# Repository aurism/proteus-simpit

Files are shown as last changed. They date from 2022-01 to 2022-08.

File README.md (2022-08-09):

# Proteus Simpit
Proteus is a flight simpit designed to fit under a standard rolling office chair, and can mount different joystick, throttle, collective, and rudder modules. Legs on the simpit frame hold the chair suspended in the air, guaranteeing that the seat will not roll or rotate. The simpit folds up when not in use, and features retractable wheels to allow the setup to easily roll out of the way. The frame is constructed mostly from off the shelf aluminum framing components.

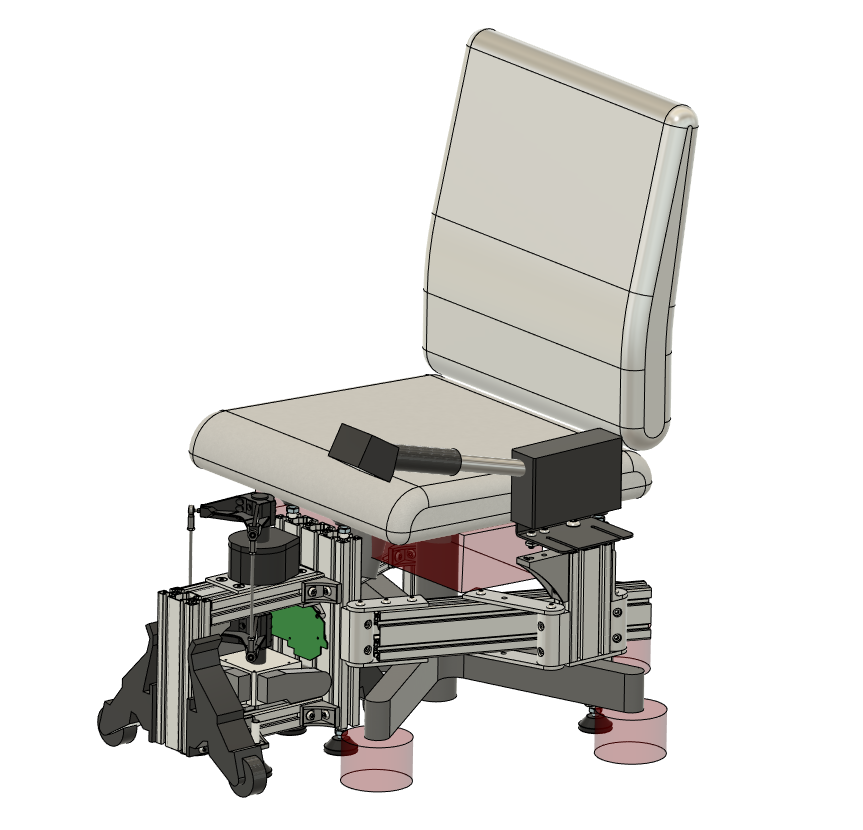
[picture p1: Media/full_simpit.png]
Full Simpit


The Puppetmaster joystick module is the main part of the Proteus simpit. It combines the force feedback capabilities of a Microsoft Sidewinder Force Feedback 2 with the precision and increased button count of a modern flight stick. A bare Microsoft force feedback gimbal is mounted on the bottom of the Puppetmaster frame and is mechanically coupled to a flight stick on top of the frame. Because it uses the original Microsoft Force Feedback 2 PCB, all original DirectInput force feedback effects are supported. Currently, the VKB Gunfighter MkIII with stick extension is used as the flight stick, but you could modify the design to support any other flight stick with a stick extension. The Puppetmaster frame is constructed from off the shelf aluminum framing components and 3D printed parts.

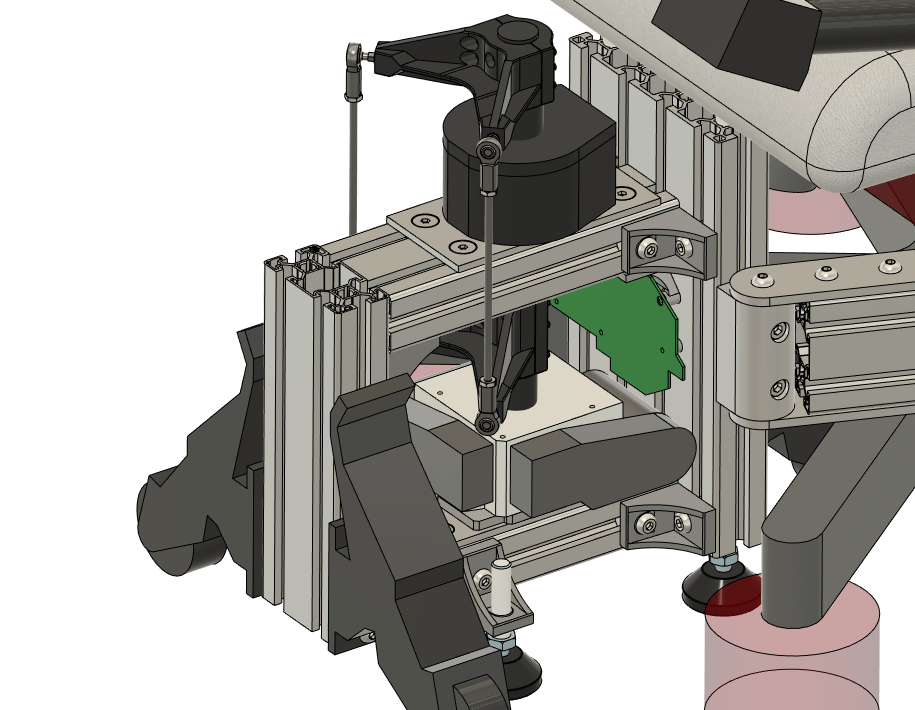
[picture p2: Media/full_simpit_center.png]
Full Simpit Center


## Current Configurations
* Proteus Simpit With All Modules
  * Mounts GF3 Puppetmaster Joystick Module in center
  * Mounts K51 Collective Module on left swingarm
  * Total cost: $1483

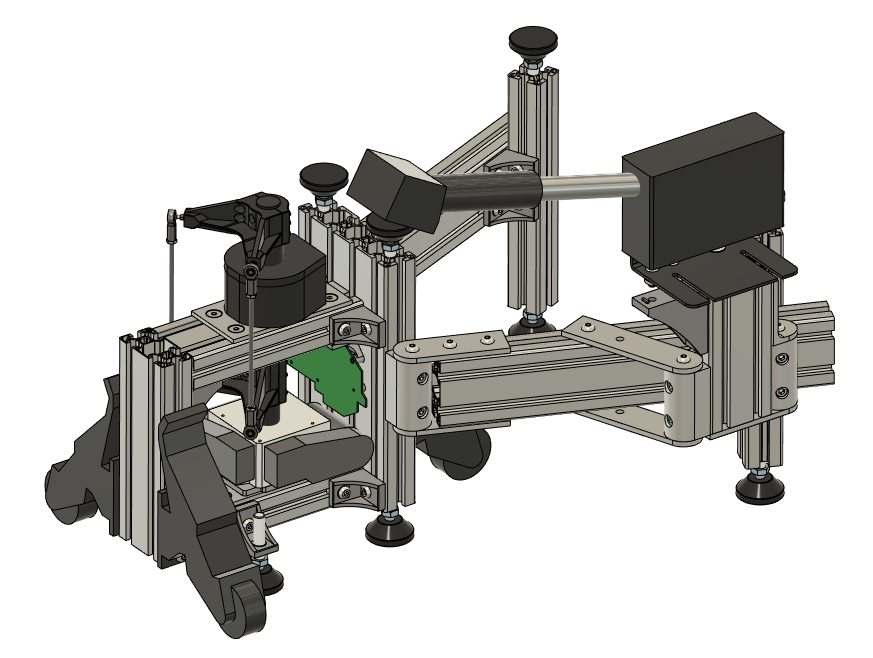
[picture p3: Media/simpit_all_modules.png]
Simpit with All Modules
  

* GF3 Puppetmaster Standalone Joystick
  * Mounts GF3 Puppetmaster Joystick Module on free standing feet
  * Total cost: $892

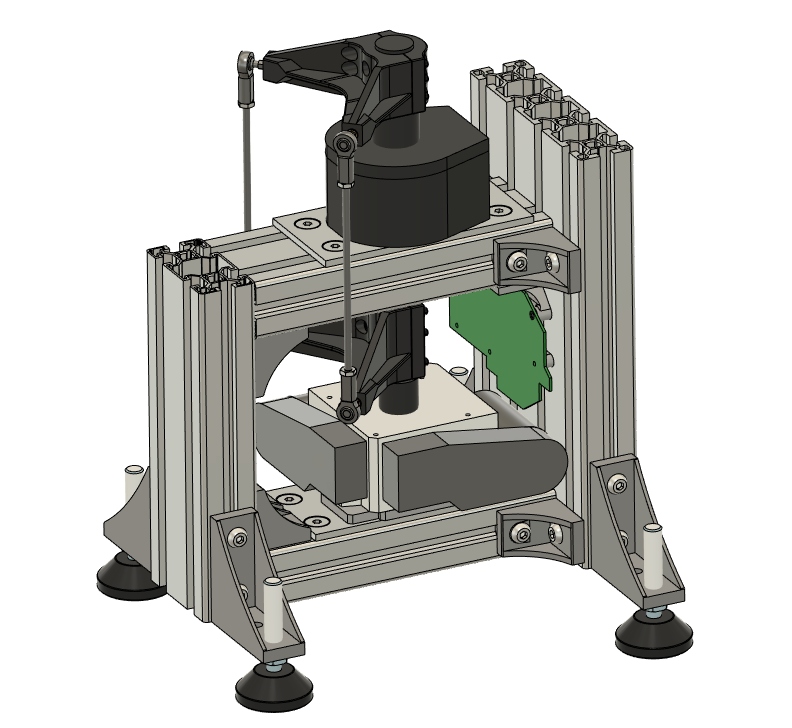
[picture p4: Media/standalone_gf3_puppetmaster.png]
Standalone GF3 Puppetmaster
  

## Current Modules
* GF3 Puppetmaster Joystick Module
  * Mounts a VKB Gunfighter MkIII with stick extension
  * Uses a Microsoft Sidewinder Force Feedback 2 gimbal
  * Cost of parts other than VKB Gunfighter MkIII: $336
  * Total cost: $795

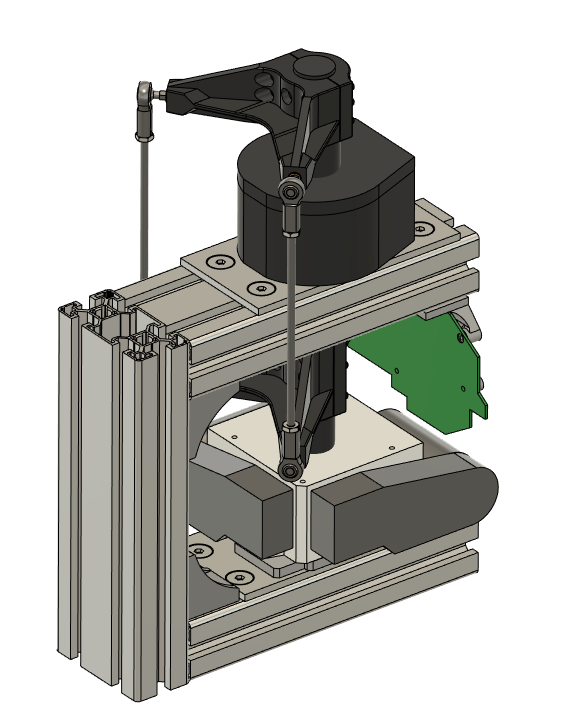
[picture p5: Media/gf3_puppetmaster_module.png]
GF3 Puppetmaster Module
  

* K51 Collective Module
  * Mounts a K-51 collective
  * Cost of parts other than K-51: $6
  * Total cost: $303

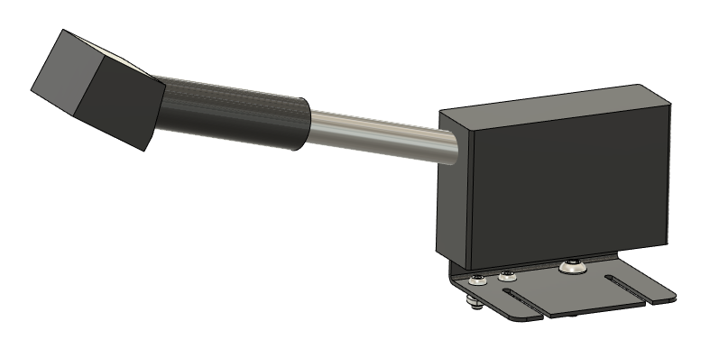
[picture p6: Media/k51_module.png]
K51 Collective Module
  

* Notionally plan to add more modules in the future

## Files and Instructions
The following files are included in each module's folder:
* CAD files, Fusion 360 and STEP format
* Drawings (if relevant)
* 3D Print Files, STL format (if relevant)
* Build instructions
* BOM

## Technical Notes
* Out of the box, the FFB gimbal does not have enough torque to adequately drive a flightstick with stick extension. Thus, the assembly instructions for the Puppetmaster joystick module includes steps to solder resistors to the FFB PCB to double the motor torque, using the method described by [Roland van Roy](http://www.simprojects.nl/ms_siderwinder_ff2_hack.htm) and others.
* With the above resistor mod, the Puppetmaster joystick produces 1.7 N-m of torque max (after subtracting torque due to friction). This feels roughly equivalent to a medium-light spring loaded cam. When held at max torque, there does not seem to be a torque falloff with time. By comparison, the Brunner CLS-E is advertised at 4.2 N-m of torque. However this [review](https://www.reddit.com/r/hoggit/comments/hu4uif/comment/fylmze2/?utm_source=share&utm_medium=web2x&context=3) states that it actually maxes out at 3.6 N-m and gradually falls off to 1.4 N-m over ~40s.
* The Puppetmaster joystick has a bit of a vague-feeling center, meaning that trimming to a certain position is less precise than desirable. Measuring from the top of the grip, the stick can be moved in roughly a 15mm diameter circle with little to no centering feeling. When the gear on the motor is clamped and prevented from turning, the stick can be moved in a roughly 7mm diameter circle freely, indicating that backlash in the mechanisms account for about half of the size of the vague center. The rest comes from the motor itself, potentially due to cogging.
* There seem to be three main sources of backlash in the Puppetmaster joystick FFB mechanism - slop in the rod ends, gap between teeth of the FFB gears, gap between the ID of the FFB gears and their axles, and cogging in the FFB motors. Using rod ends with tight nylon or teflon races essentially eliminates the first source.
* The Gunfighter MkIII gimbal has about +/-21 degrees of travel on each axis, and the FFB gimbal has about the same amount. The rod ends in the Puppetmaster mechanism have just enough angular range to accommodate this motion. When using a different top joystick with more travel, do not force it to the ends of its travel to avoid damaging the FFB gimbal or the rod ends.
* With the additional weight of the Puppetmaster linkages attached to it, the Gunfighter stick will tilt under its own weight. However, using VKB soft space cams along with #10 springs will balance out the effect of gravity and prevent this tilting.
* For adjustable damping, friction, and force trim effects, you can use [SimFFB](https://github.com/joeyjojojunior/simFFB). Note that SimFFB makes an exclusive connection to the FFB stick. You can either have SimFFB or the flight sim control force feedback effects, but not both.

## Support
* For general discussion and help, feel free to leave a post in the [Discussions board](https://github.com/aurism/proteus-simpit/discussions).
* If you find an issue with the design or instructions, please open an [Issue report](https://github.com/aurism/proteus-simpit/issues).

## Videos
* [Force Feedback Test](https://youtu.be/MUK2omoil2U)

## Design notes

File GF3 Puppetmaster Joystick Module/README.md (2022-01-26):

# GF3 Puppetmaster Joystick Module Assembly Instructions
## General Notes
* Refer to CAD for final location of each part.
* Any hardware can be replaced with an alternative part that fit on assembly.
* Aluminum framing parts can be replaced by equivalent alternatives from other vendors. The current design uses 40mm standard framing parts, but 1.5 inch standard framing parts will also work, as long as all other framing parts are switched to their 1.5 inch equivalents, and the GF3 mounting plate and FFB mounting plate have their hole patterns updated.
* Check the BOM against current CAD before purchasing parts.

## Tools required
* Small Phillips screwdriver
* Soldering iron and solder
* 22 AWG stranded wire or similar
* Heat shrink tube
* Hacksaw or other method of cutting 3/16" aluminum sheet
* Center punch
* Drill and drill bits
* 90 degree countersink bit
* Set of metric Allen keys
* 2X Small adjustable wrenches

## Instructions
### Prepare Gunfighter Gimbal
1. Disassemble the Gunfighter gimbal per [VKB instructions](https://www.youtube.com/watch?v=dc8LZyThYs0) and install a soft center space cam (Space-S) and one #10 spring on each axis. This balances out the weight of the final joystick and prevents it from tilting.
2. For maximum force feedback (at the cost of feeling the motors cogging and gear teeth meshing), loosen the dry clutches all the way. Alternatively, for smoother force feedback (at the cost of lower force), tighten the dry clutches part of the way.
3. Reassemble the Gunfighter gimbal.

### Prepare FFB Gimbal
1. Ensure FFB stick works correctly before disassembly.
2. Unplug FFB stick and open its case. Some of the screws have a special cross feature that make them difficult to untorque, unscrew these slowly while pushing down on them.
3. Unscrew and remove the power PCB (the one that the power cable connects to). Take care not to touch any of the solder joints or PCB traces as the capacitors may still carry charge.
4. Unplug the connector on the power PCB that attaches it to the main PCB (the one with the Microsoft logo).
5. Unplug all electrical connectors from the main PCB and remove it, retaining all its fasteners for later use. Note that the USB cable is soldered to the board and will stay connected.
6. Unscrew the handle from the gimbal and remove the handle by passing its electrical connectors through the center tube.
7. Unscrew the gimbal from the case and set aside.
8. The gimbal motors contain magnets which can attract loose hardware into the motor vent holes. Cover these holes with tape, to be removed later after assembly is complete.

### Modify FFB PCB
1. Solder one 1-ohm current sense resistor on top of each of 8X resistors marked in the picture.\
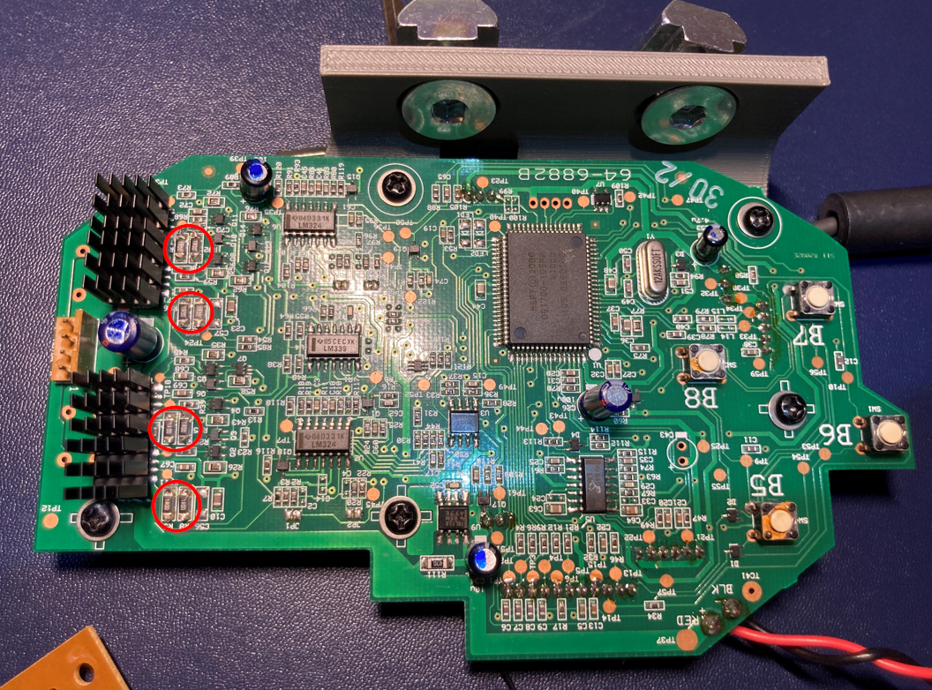
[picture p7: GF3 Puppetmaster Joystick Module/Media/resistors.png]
Solder Resistors

2. Clean the tops of the FETs with isopropanol and attach a self adhesive heat sink to each one.
3. Solder short 22 AWG wires to the purchased power connector header. Connect these wires to the barrel connector that comes with the purchased 24V power supply. Ensure that the red wire (positive) coming from the main PCB is connected to the center pin of the barrel connector.
4. Apply heat shrink tube over these wires.

### Print and Assemble 3D Printed Parts
1. 3D print the parts in the "3D Print Files" folder. STL files are in millimeter units. Recommended print orientation shown below. I used ABS with 50% infill, which felt sturdy under operation. Other printed materials will likely also work, but I'd recommend no less than 50% infill for stiffness.\
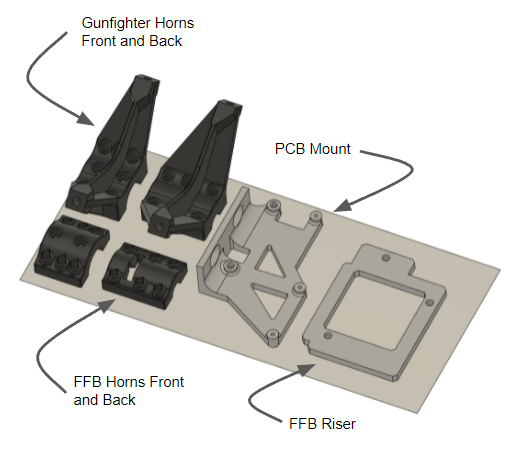
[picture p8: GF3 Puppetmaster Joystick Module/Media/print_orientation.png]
Print Orientations

2. Heat up the heat set inserts and press them into the holes at the end of the FFB front horns and Gunfighter front horns.\
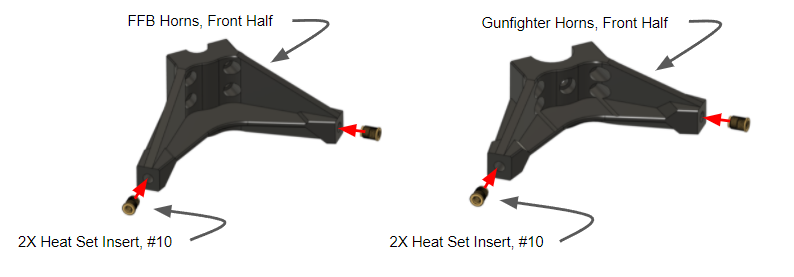
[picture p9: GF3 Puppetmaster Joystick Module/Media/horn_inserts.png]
Install FFB and Gunfighter Horn Inserts

3. Attach Gunfighter Horns to the Gunfighter stick extension using the 6x #10-32 socket head cap screws and the two original screws at the base of the stick extension. Do not overtighten the 6x #10-32 screws to avoid cracking these printed parts.\
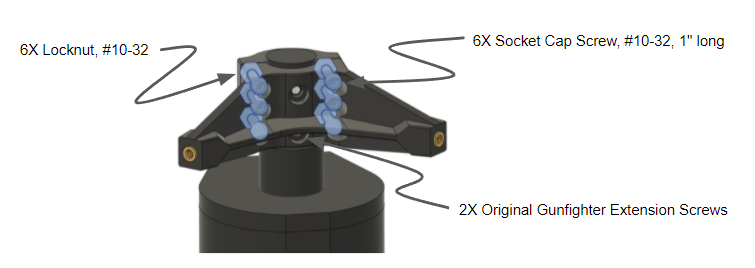
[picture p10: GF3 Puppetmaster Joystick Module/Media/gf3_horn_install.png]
Install GF3 Horns

4. Attach FFB Horns to the FFB stick base using the 6x #10-32 socket head cap screws. Do not overtighten the screws to avoid cracking these printed parts.\
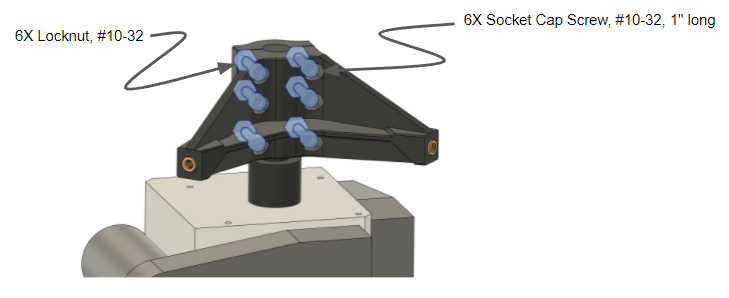
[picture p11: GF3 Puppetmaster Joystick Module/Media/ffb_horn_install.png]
Install FFB Horns

5. Attach FFB PCB to the PCB Mount using the original screws from the PCB\
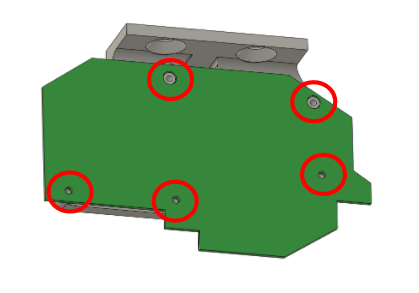
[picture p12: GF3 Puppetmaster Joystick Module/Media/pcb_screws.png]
Install PCB Screws


### Assemble Tie Rods
1. Apply lithium grease or other light grease to the rod end sphericals, and rotate the sphericals so that they are uniformly greased.\
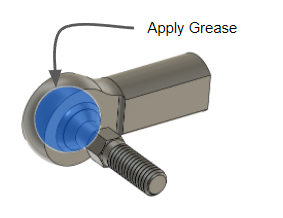
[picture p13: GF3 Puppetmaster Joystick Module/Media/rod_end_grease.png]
Rod End Grease

2. Install jamnuts and rod ends on each end of both threaded rods. Adjust rod ends so that there is 136.5mm of separation between rod ends. Do not torque jamnuts yet, leave them loose.\
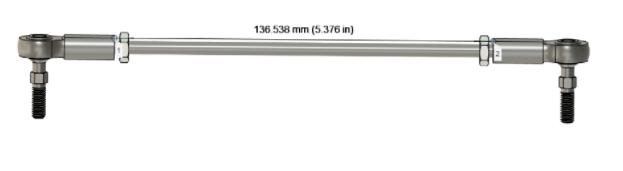
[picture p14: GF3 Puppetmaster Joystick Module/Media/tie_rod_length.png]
Tie Rod Length


### Mount Gimbals
1. Cut the 3" x 12" aluminum sheet into two 3" x 6" pieces.
2. Print "GF3 Mounting Plate Drawing.pdf" at actual size. Tape one of the aluminum sheets to this printout and center punch the hole locations.
3. Drill the aluminum sheet per the drawing. Countersink holes using 90 degree tip countersink bit.\
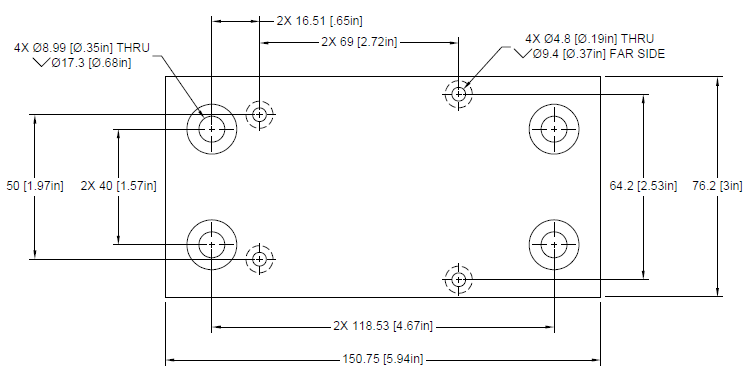
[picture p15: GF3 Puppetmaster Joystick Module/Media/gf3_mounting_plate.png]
Gunfighter Mounting Plate

4. Print "FFB Mounting Plate 2 Drawing.pdf" at actual size. Tape the other aluminum sheet to this printout and center punch the hole locations.
5. Drill the aluminum sheet per the drawing. Countersink holes using 90 degree tip countersink bit.\
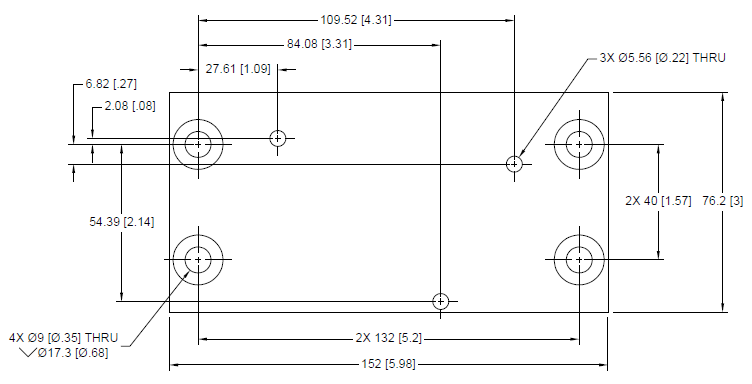
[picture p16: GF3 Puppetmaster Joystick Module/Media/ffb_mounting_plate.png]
FFB Mounting Plate

6. Attach Gunfighter gimbal to the GF3 Mounting Plate using its 4x original screws.\
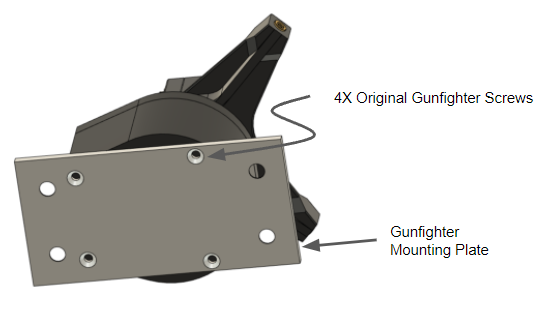
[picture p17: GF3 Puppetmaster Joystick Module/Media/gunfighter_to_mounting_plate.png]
Attach Gunfighter to Mounting Plate

7. Attach the FFB Riser and FFB Mounting Plate to the FFB gimbal using the #4 screws and washers.\
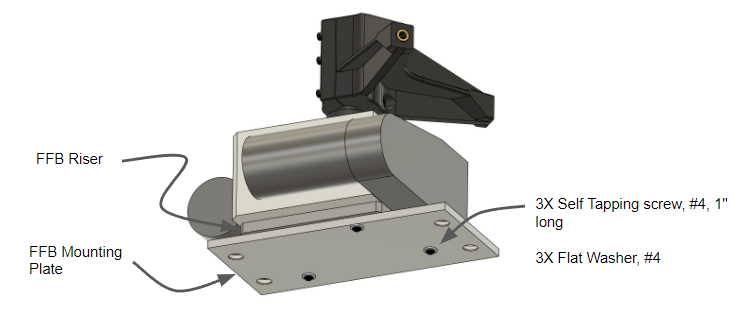
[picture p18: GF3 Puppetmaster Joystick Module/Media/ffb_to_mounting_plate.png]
Attach FFB to Mounting Plate


### Drill FFB Beam
1. Print "Drilled Bottom Beam Drawing.pdf" at actual size. Tape the bottom beam PN HFSL8-4080-215 to this printout and center punch the hole locations.
2. Pilot drill each location with a 3mm or equivalent bit, then countersink each hole for a final OD of roughly 10mm. The partial hole is pretty weird, I had to pilot drill at the edge of where the final countersink should end up, and then run the countersink bit into this pilot hole at an angle.\
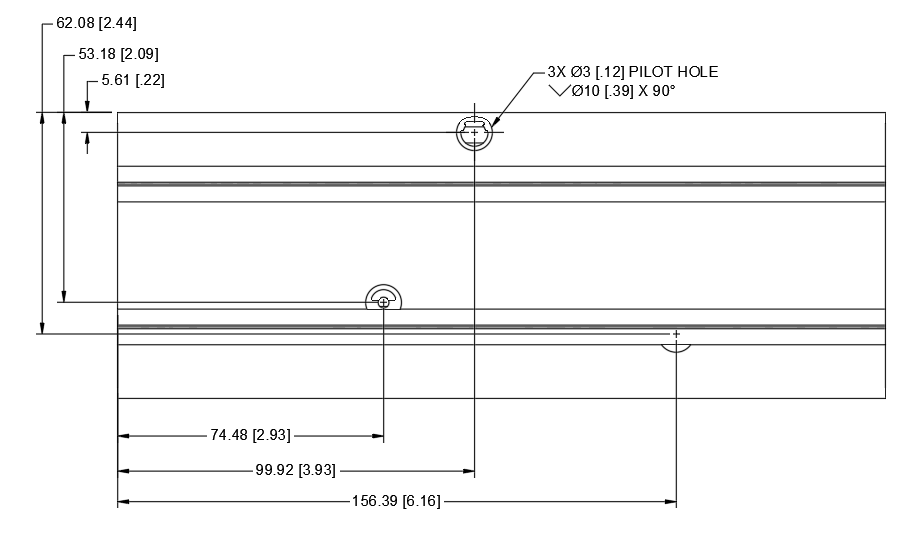
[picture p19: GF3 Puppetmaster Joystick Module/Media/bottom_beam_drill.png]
Drill Bottom Beam
\
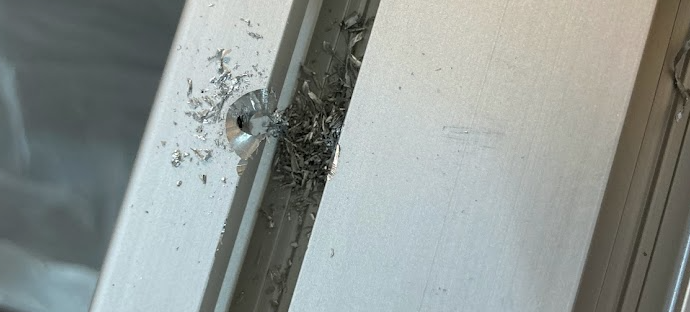
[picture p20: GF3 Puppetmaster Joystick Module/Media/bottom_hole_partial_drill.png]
Partial Hole Drill


### Assemble Puppetmaster Joystick Module
1. Temporarily unscrew and detach the rear motor from the FFB gimbal. The gear attached to the shaft prevents the motor from coming completely off, but having it hang loose provides enough room to torque the screws in the next step.\
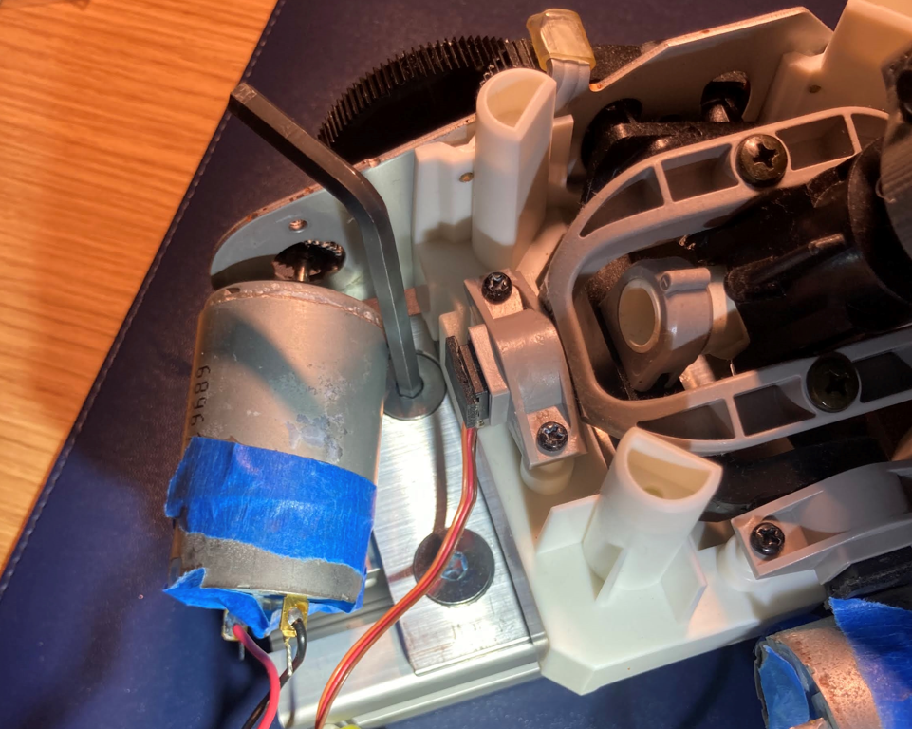
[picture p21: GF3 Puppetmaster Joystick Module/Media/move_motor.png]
Move Motor

2. Install flat head screws and slot nuts to the 4x mounting holes on the FFB Mounting Plate. Slide this mounting plate onto its aluminum beam leaving 21mm between the rear of the mounting plate and the beam, then torque the flat head screws. Reattach the rear motor to the FFB gimbal.\
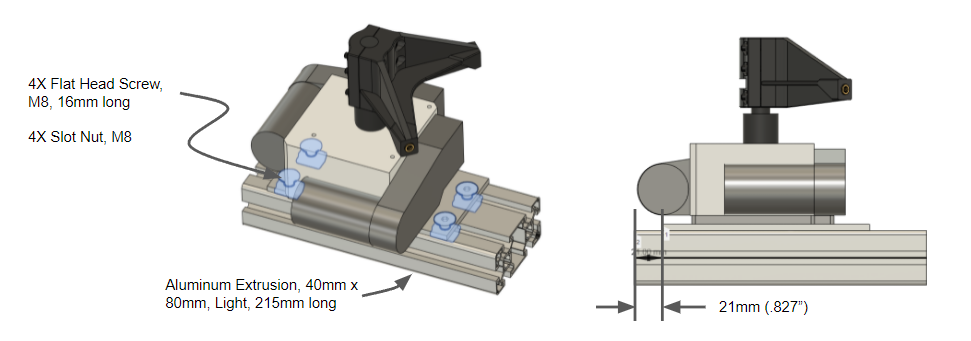
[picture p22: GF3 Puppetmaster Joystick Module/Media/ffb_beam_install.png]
FFB beam Install

3. Install flat head screws and slot nuts to the 4x mounting holes on the Gunfighter Mounting Plate. Slide this mounting plate onto its aluminum beam, leaving 12.7mm between the rear of the mounting plate and the beam, then torque the flat head screws.\
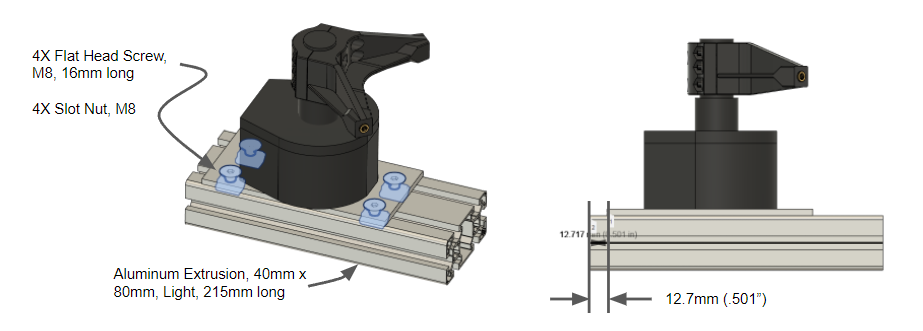
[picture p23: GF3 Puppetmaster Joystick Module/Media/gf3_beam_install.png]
Gunfighter beam Install

4. Install flat head screws and slot nuts to the 2x mounting holes on the PCB Mount. Slide mount onto its aluminum beam, leaving 7.9mm between the rear of the mount and the beam, then torque the flat head screws.\
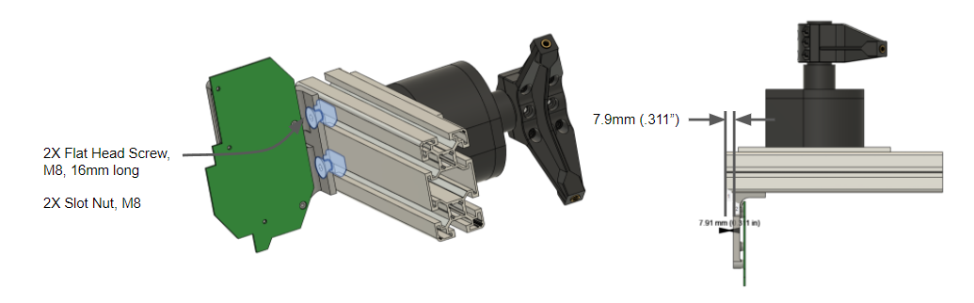
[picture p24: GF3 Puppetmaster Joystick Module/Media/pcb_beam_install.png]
PCB beam Install

5. Attach the front vertical aluminum beam to the Gunfighter and FFB aluminum beams using the right angle brackets. Leave 152mm between top beam and bottom beam. Ensure all beams are aligned flush with one another, then torque fasteners.\
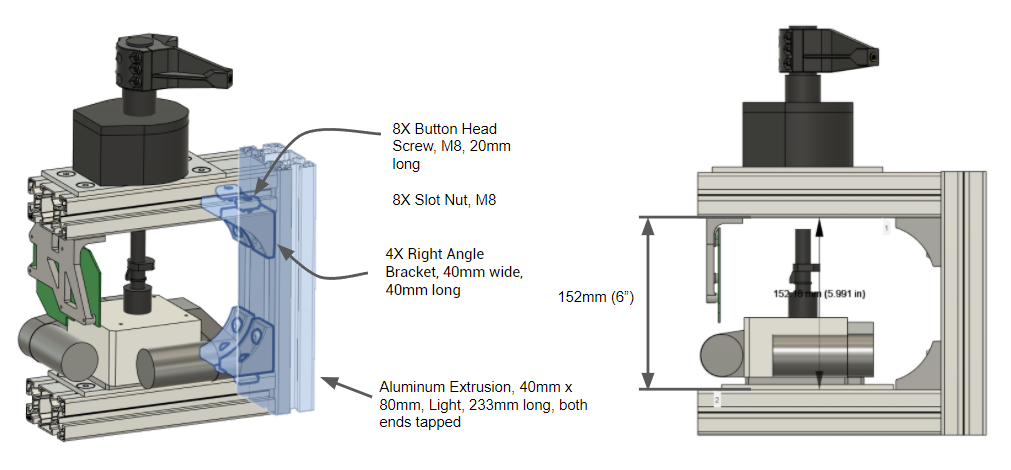
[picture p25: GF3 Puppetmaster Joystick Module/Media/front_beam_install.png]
Front Aluminum beam Install

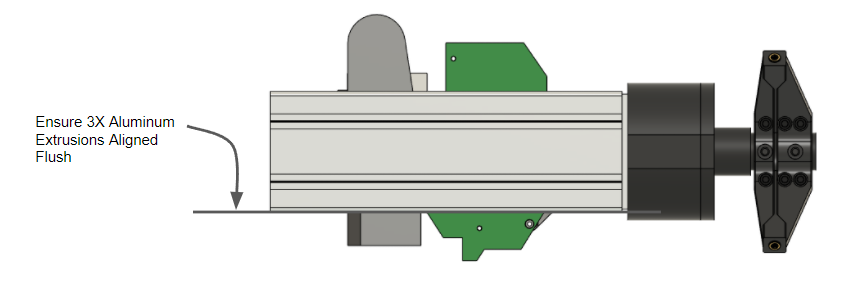
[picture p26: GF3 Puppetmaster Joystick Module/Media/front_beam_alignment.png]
Front Aluminum beam Alignment

6. Attach the FFB motor and potentiometer wires to the FFB PCB
7. Check if the Gunfighter gimbal is centered vertically over the FFB gimbal. If not, loosen the Gunfighter flat head screws, adjust the location of the Gunfighter gimbal, then retighten the screws.\
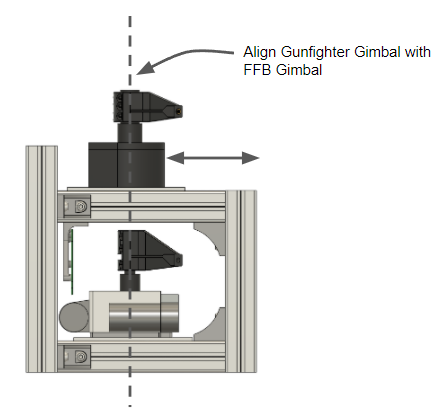
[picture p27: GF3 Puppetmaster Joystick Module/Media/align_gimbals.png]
Align Gimbals

8. Install the tie rods into the Gunfighter horns and FFB horns part way, do not fully torque. Move the Gunfighter gimbal through its entire range of motion and note in when the FFB gimbal hits its hard stops. Remove tie rods and adjust their lengths so that the FFB gimbal hit its hard stops exactly when the Gunfighter gimbal hits its hard stops.\
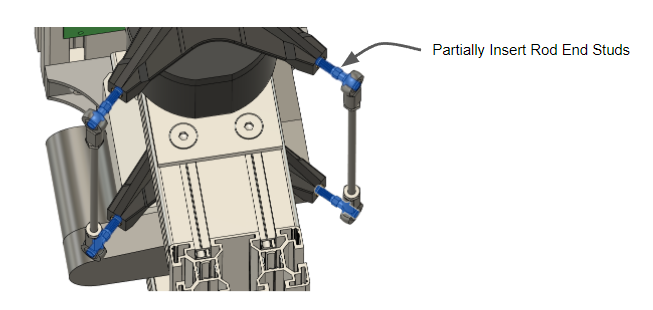
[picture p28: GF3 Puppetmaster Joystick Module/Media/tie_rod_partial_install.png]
Tie Rod Partial Install

9. Screw the rod ends into the Gunfighter horns and FFB horns fully, torque until snug. Do not overtorque to avoid damaging the printed parts. Tighten jamnuts.\
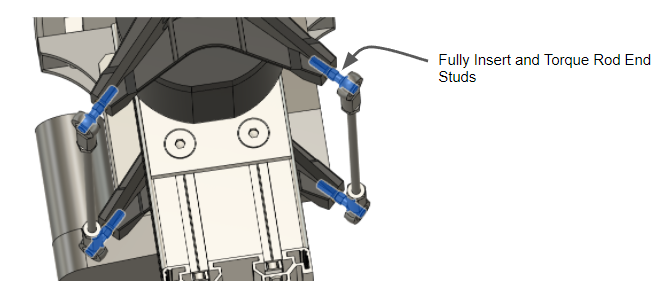
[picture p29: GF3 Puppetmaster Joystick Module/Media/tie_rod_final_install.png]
Tie Rod Final Install

10. Remove protective tape from FFB motors. Plug USB connector into computer and plug 24V power supply into barrel connector. Ensure FFB gimbal is working correctly and providing force feedback.

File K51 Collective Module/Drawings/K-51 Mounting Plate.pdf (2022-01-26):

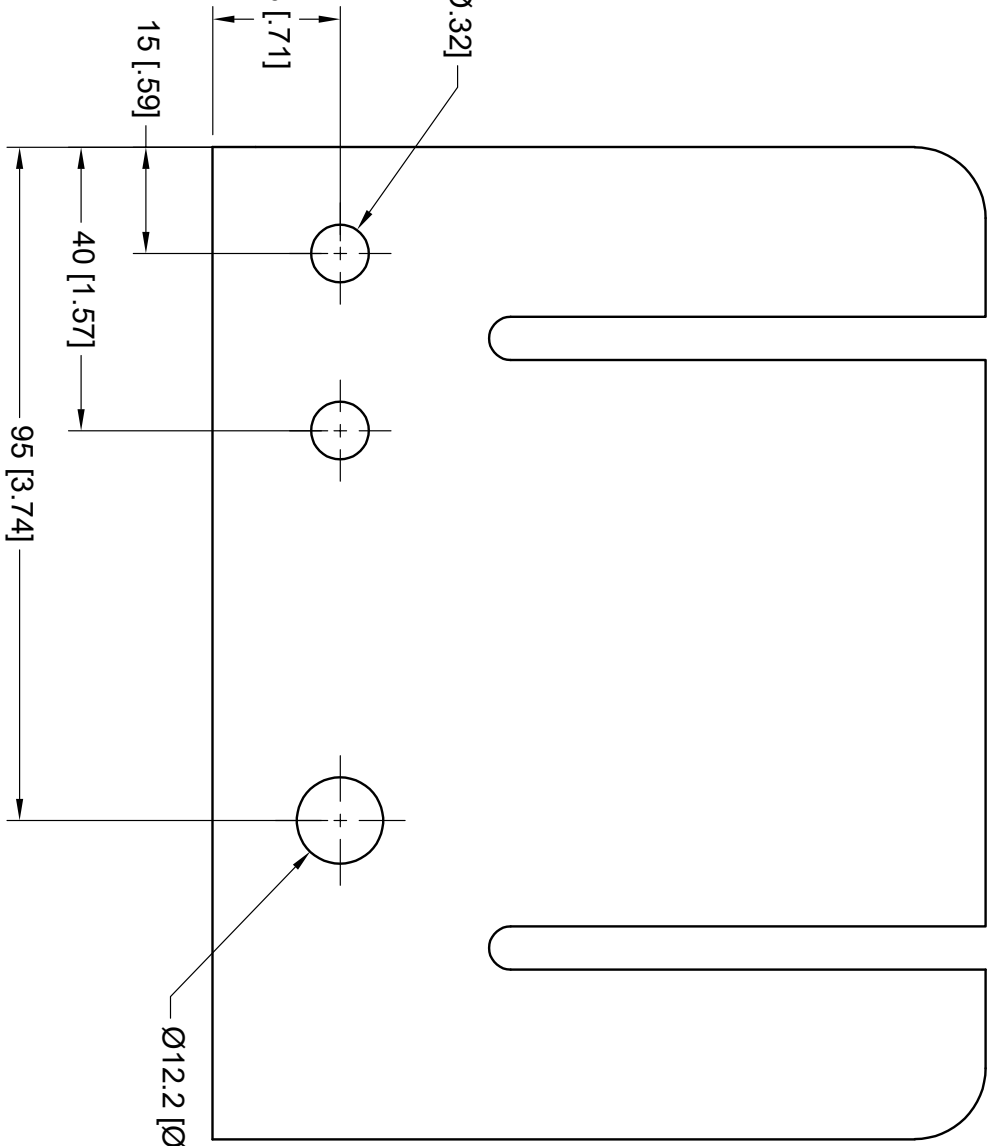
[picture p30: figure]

18 [.71] 15 [.59] 40 [1.57] 95 [3.74] 2X Ø8.2 [Ø.32] Ø12.2 [Ø.48]


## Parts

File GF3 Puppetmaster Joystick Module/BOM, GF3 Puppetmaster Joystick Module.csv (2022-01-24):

Description | PN | Qty Needed | Per Pkg Price | Per Pkg Qty | Num Pkgs | Total | Notes | Link
Aluminum Extrusion, 40mm x 80mm, Light, 233mm long, both ends tapped | HFSL8-4080-233-TPW | 1 | $17.13 | 1 | 1 | $17.13 |  | https://us.misumi-ec.com/vona2/detail/110302690310/?ProductCode=HFSL8-4080-233-TPW
Aluminum Extrusion, 40mm x 80mm, Light, 215mm long | HFSL8-4080-215 | 2 | $8.81 | 1 | 2 | $17.62 |  | https://us.misumi-ec.com/vona2/detail/110302690310/?ProductCode=HFSL8-4080-215
Right Angle Bracket, 40mm wide, 40mm long | HBLFSNF8 | 4 | $0.85 | 1 | 4 | $3.40 |  | https://us.misumi-ec.com/vona2/detail/110300449520/?ProductCode=HBLFSNF8
Button Head Screw, M8, 20mm long | HBCBM8-20 | 8 | $0.95 | 1 | 8 | $7.60 |  | https://us.misumi-ec.com/vona2/detail/110302261550/?ProductCode=HBCBM8-20
Flat Head Screw, M8, 16mm long | HFBCM8-16 | 10 | $0.72 | 1 | 10 | $7.20 |  | https://us.misumi-ec.com/vona2/detail/110300463610/?ProductCode=HFBCM8-16
Slot Nut, M8 | HNTT8-8 | 18 | $0.66 | 1 | 18 | $11.88 |  | https://us.misumi-ec.com/vona2/detail/110302256040/?ProductCode=HNTT8-8
Aluminum Sheet, .1875" Thick, 3"x12" | 8975K85 | 1 | $6.12 | 1 | 1 | $6.12 | Cut and drill per project instructions | https://www.mcmaster.com/8975K85-8975K699/
Heat Set Insert, #10 | 97171A220 | 4 | $15.71 | 50 | 1 | $15.71 |  | https://www.mcmaster.com/97171A220/
Rod End, #10 female, #10 stud, nylon race | MPF-3S | 4 | $7.76 | 1 | 4 | $31.04 |  | https://midwestcontrol.com/shop/MPF-3S
Externally Threaded Rod, #10, 6" long | 90322A644 | 2 | $2.85 | 1 | 2 | $5.70 |  | https://www.mcmaster.com/90322A644/
Socket Cap Screw, #10-32, 1" long | 96006A696 | 12 | $6.90 | 25 | 1 | $6.90 |  | https://www.mcmaster.com/96006A696/
Self Tapping screw, #4, 1" long | 99461A208 | 3 | $8.50 | 25 | 1 | $8.50 |  | https://www.mcmaster.com/99461A208/
Locknut, #10-32 | 90633A411 | 12 | $3.18 | 100 | 1 | $3.18 |  | https://www.mcmaster.com/90633A411/
Jamnut, #10-32, RH | 90480A195 | 4 | $1.89 | 100 | 1 | $1.89 |  | https://www.mcmaster.com/90480a195/
Flat Washer, #4 | 92141A005 | 3 | $1.43 | 100 | 1 | $1.43 |  | https://www.mcmaster.com/92141A005/
24V Power Supply | B01GC6VS8I | 1 | $20.99 | 1 | 1 | $20.99 |  | https://smile.amazon.com/dp/B01GC6VS8I
Self Adhesive Heat Sink | 20188 | 4 | $0.93 | 1 | 4 | $3.72 |  | https://www.digikey.com/en/products/detail/watterott-electronic-gmbh/20188/10071165
Resistor, Current Sense, 1 ohm | CRM1206-FX-1R00ELF | 4 | $0.32 | 1 | 4 | $1.28 |  | https://www.mouser.com/ProductDetail/Bourns/CRM1206-FX-1R00ELF?qs=gtReTMvImqn8T1bwG81BBg%3D%3D
Power connector header | IL-G-3P-S3T2-SA | 1 | $0.45 | 1 | 1 | $0.45 |  | https://www.digikey.com/en/products/detail/jae-electronics/IL-G-3P-S3T2-SA/2523363
FFB Horns, front half |  | 1 | $14.04 | 1 | 1 | $14.04 | 3D print per project instructions. Price shown is estimate for printing using online service
FFB Horns, rear half |  | 1 | $14.04 | 1 | 1 | $14.04 | 3D print per project instructions. Price shown is estimate for printing using online service
Gunfighter Horns, front half |  | 1 | $14.04 | 1 | 1 | $14.04 | 3D print per project instructions. Price shown is estimate for printing using online service
Gunfighter Horns, rear half |  | 1 | $14.04 | 1 | 1 | $14.04 | 3D print per project instructions. Price shown is estimate for printing using online service
PCB Mount |  | 1 | $14.04 | 1 | 1 | $14.04 | 3D print per project instructions. Price shown is estimate for printing using online service
FFB Riser |  | 1 | $14.04 | 1 | 1 | $14.04 | 3D print per project instructions. Price shown is estimate for printing using online service
 |  |  |  |  | Hardware Subtotal | $255.97
VKB Gunfighter MkIII Gimbal with Extension |  | 1 | $459.00 | 1 | 1 | $459.00 | Prepare per project instructions. Price listed is for Modern Combat grip with long extension, but both extensions and any grip works | https://vkbcontrollers.com/?product=gunfighter-mk-ii
Microsoft Sidewinder Force Feedback 2 Gimbal and PCB |  | 1 | $80.00 | 1 | 1 | $80.00 | Prepare per project instructions. Price listed is approx price for used joystick | https://www.ebay.com/sch/i.html?_nkw=Microsoft%20SideWinder%20Force%20Feedback%202&ssPageName=GSTL
 |  |  |  |  | Grand Total | $794.97

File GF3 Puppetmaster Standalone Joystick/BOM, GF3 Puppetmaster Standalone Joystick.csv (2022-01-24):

Description | PN | Qty Needed | Per Pkg Price | Per Pkg Qty | Num Pkgs | Total | Notes | Link
Aluminum Extrusion, 40mm x 160mm, 290mm long | HFS8-40160-290-TPW | 1 | $37.58 | 1 | 1 | $37.58 | Drill per project instructions | https://us.misumi-ec.com/vona2/detail/110302691170/?ProductCode=HFS8-40160-290-TPW
Right Angle Bracket, 40mm wide, 80mm long | HBLFSSW8 | 4 | $4.34 | 1 | 4 | $17.36 | Cut per project instructions | https://us.misumi-ec.com/vona2/detail/110300449770/?ProductCode=HBLFSSW8
Right Angle Bracket, 40mm wide, 40mm long | HBLFSNF8 | 4 | $0.85 | 1 | 4 | $3.40 | Cut and drill per project instructions | https://us.misumi-ec.com/vona2/detail/110300449520/?ProductCode=HBLFSNF8
Button Head Screw, M8, 20mm long | HBCBM8-20 | 16 | $0.95 | 1 | 16 | $15.20 |  | https://us.misumi-ec.com/vona2/detail/110302261550/?ProductCode=HBCBM8-20
Slot Nut, M8 | HNTT8-8 | 16 | $0.66 | 1 | 16 | $10.56 |  | https://us.misumi-ec.com/vona2/detail/110302256040/?ProductCode=HNTT8-8
Leveling Feet Set, M12, 1.9" OD, 1.9" long | B08GS86L7T | 4 | $12.89 | 4 | 1 | $12.89 |  | https://smile.amazon.com/gp/product/B08GS86L7T
 |  |  |  |  | Hardware Subtotal | $96.99
GF3 Puppetmaster Module |  | 1 | $794.97 | 1 | 1 | $794.97 | See corresponding BOM for parts
 |  |  |  |  | Grand Total | $891.96

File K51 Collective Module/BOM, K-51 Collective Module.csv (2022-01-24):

Description | PN | Qty Needed | Per Pkg Price | Per Pkg Qty | Num Pkgs | Total | Notes | Link
Button Head Screw, M12, 35mm long | HBCBM12-35 | 1 | $2.95 | 1 | 1 | $2.95 |  | https://us.misumi-ec.com/vona2/detail/110302261550/?ProductCode=HBCBM12-35
Button Head Screw, M8, 20mm long | HBCBM8-20 | 2 | $0.95 | 1 | 2 | $1.90 |  | https://us.misumi-ec.com/vona2/detail/110302261550/?ProductCode=HBCBM8-20
Slot Nut, Economy, M8 | 40-1981 | 2 | $0.43 | 1 | 2 | $0.86 |  | https://8020.net/40-1981.html
 |  |  |  |  | Hardware Subtotal | $5.71
K-51 Collective |  | 1 | $297.00 | 1 | 1 | $297.00 |  | https://forums.eagle.ru/topic/222296-sollective-pitch-control-lever/
 |  |  |  |  | Grand Total | $302.71

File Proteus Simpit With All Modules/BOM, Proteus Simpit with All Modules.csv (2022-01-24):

Description | PN | Qty Needed | Per Pkg Price | Per Pkg Qty | Num Pkgs | Total | Notes | Link
Aluminum Extrusion, 40mm x 160mm, 290mm long | HFS8-40160-290-TPW | 1 | $37.58 | 1 | 1 | $37.58 | Drill per project instructions | https://us.misumi-ec.com/vona2/detail/110302691170/?ProductCode=HFS8-40160-290-TPW
Aluminum Extrusion, 40mm x 40mm, 272mm long, both ends tapped | HFSP8-4040-272-TPW | 2 | $19.27 | 1 | 2 | $38.54 |  | https://us.misumi-ec.com/vona2/detail/110302691870/?ProductCode=HFSP8-4040-272-TPW
Aluminum Extrusion, 40mm x 80mm, Light, 420mm long | HFSL8-4080-420 | 2 | $13.73 | 1 | 2 | $27.46 |  | https://us.misumi-ec.com/vona2/detail/110302690310/?ProductCode=HFSL8-4080-420
Aluminum Extrusion, 40mm x 80mm, Light, 170mm long, both ends tapped | HFSL8-4080-170-TPW | 1 | $8.81 | 1 | 1 | $8.81 |  | https://us.misumi-ec.com/vona2/detail/110302690310/?ProductCode=HFSL8-4080-170-TPW
Pivot Nub and Screw kit, 40mm x 80mm | 40-4386 | 4 | $12.20 | 1 | 4 | $48.80 |  | https://8020.net/40-4386.html
L Pivot Arm, 40mm | 40-4349 | 1 | $7.33 | 1 | 1 | $7.33 |  | https://8020.net/40-4349.html
Straight Pivot Arm, 40mm | 40-4396 | 5 | $7.33 | 1 | 5 | $36.65 | Drill per project instructions | https://8020.net/40-4396.html
Straight Pivot Arm, Extended, 40mm | 40-4399 | 2 | $7.60 | 1 | 2 | $15.20 |  | https://8020.net/40-4399.html
Right Angle Bracket, 40mm wide, 80mm long | HBLFSSW8 | 1 | $4.34 | 1 | 1 | $4.34 | Cut per project instructions | https://us.misumi-ec.com/vona2/detail/110300449770/?ProductCode=HBLFSSW8
Right Angle Bracket, 40mm wide, 40mm long | HBLFSNF8 | 10 | $0.85 | 1 | 10 | $8.50 |  | https://us.misumi-ec.com/vona2/detail/110300449520/?ProductCode=HBLFSNF8
Button Head Screw, M12, 35mm long | HBCBM12-35 | 2 | $2.95 | 1 | 2 | $5.90 |  | https://us.misumi-ec.com/vona2/detail/110302261550/?ProductCode=HBCBM12-35
Button Head Screw, M8, 20mm long | HBCBM8-20 | 22 | $0.95 | 1 | 22 | $20.90 |  | https://us.misumi-ec.com/vona2/detail/110302261550/?ProductCode=HBCBM8-20
Button Head Screw, M8, 16mm long | 19-8316 | 24 | $0.38 | 1 | 24 | $9.12 |  | https://8020.net/19-8316.html
Slot Nut, M8 | HNTT8-8 | 32 | $0.66 | 1 | 32 | $21.12 |  | https://us.misumi-ec.com/vona2/detail/110302256040/?ProductCode=HNTT8-8
Slot Nut, Economy, M8 | 40-1981 | 2 | $0.43 | 1 | 2 | $0.86 | Cut per project instructions | https://8020.net/40-1981.html
Retractable Caster Set | 17001 | 3 | $54.69 | 4 | 1 | $54.69 |  | https://www.homedepot.com/p/POWERTEC-New-Workbench-Caster-Kit-4-Pack-17001/307723909
Leveling Feet Set, M12, 1.9" OD, 1.9" long | B08GS86L7T | 10 | $12.89 | 4 | 3 | $38.67 | Cut per project instructions | https://smile.amazon.com/gp/product/B08GS86L7T
 |  |  |  |  | Hardware Subtotal | $384.47
GF3 Puppetmaster Module |  | 1 | $794.97 | 1 | 1 | $794.97 | See corresponding BOM for parts
K-51 Module |  | 1 | $302.71 | 1 | 1 | $302.71 | See corresponding BOM for parts
 |  |  |  |  | Grand Total | $1,482.15

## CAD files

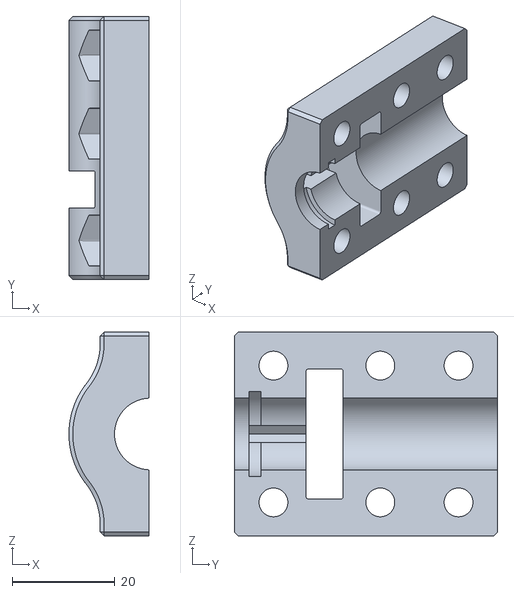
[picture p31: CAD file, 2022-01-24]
GF3 Puppetmaster Joystick Module/3D Print Files/FFB Horns, Rear Half.stl
15.6 x 51.3 x 39.8

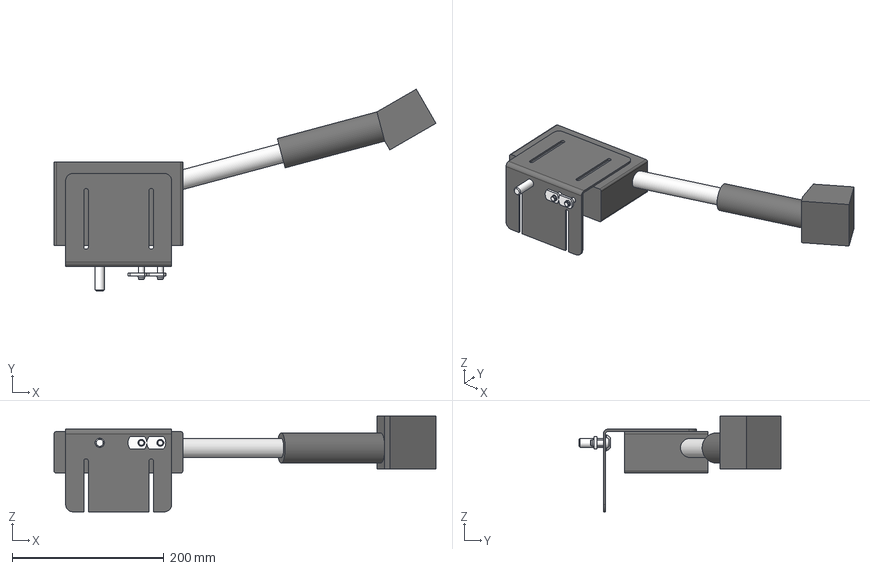
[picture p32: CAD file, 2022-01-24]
K51 Collective Module/K51 Collective Module.step
503.9 x 266.1 x 126.3 mm
91306A795_NO THREADS_Button Head Hex Drive Screws
HBCBM8-20 x 2
K-51 Mounting Bracket
K-51 Collective

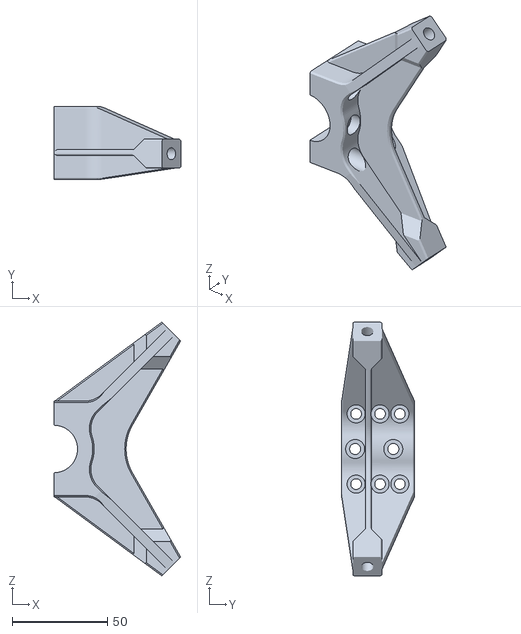
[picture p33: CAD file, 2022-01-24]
GF3 Puppetmaster Joystick Module/3D Print Files/Gunfighter Horns, Front Half.stl
66.5 x 38.3 x 133.6

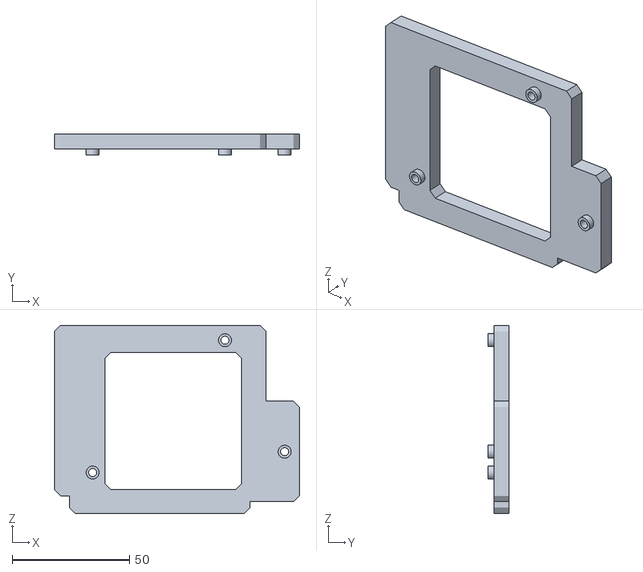
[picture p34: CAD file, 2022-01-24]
GF3 Puppetmaster Joystick Module/3D Print Files/FFB Riser.stl
104.5 x 8.89 x 80.4

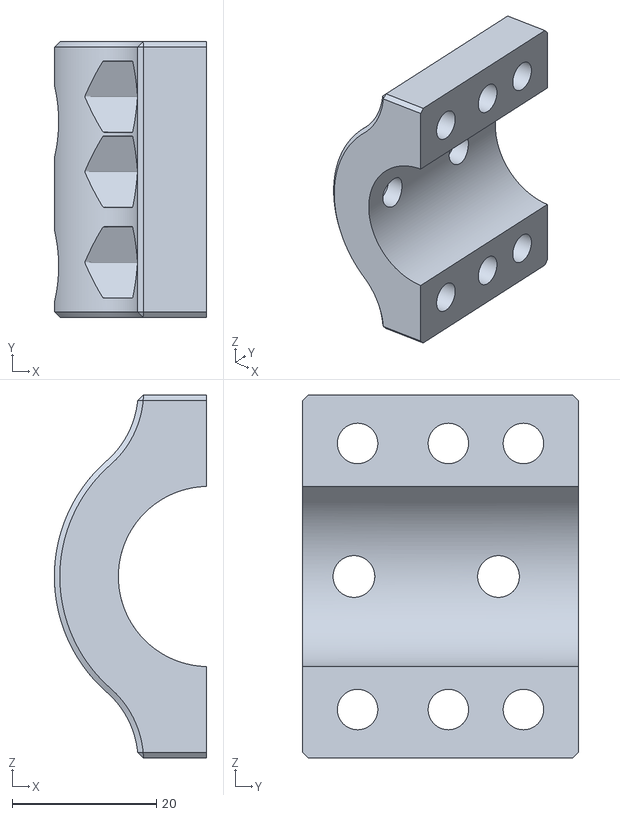
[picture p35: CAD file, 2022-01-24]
GF3 Puppetmaster Joystick Module/3D Print Files/Gunfighter Horns, Rear Half.stl
21.1 x 38.3 x 50.4

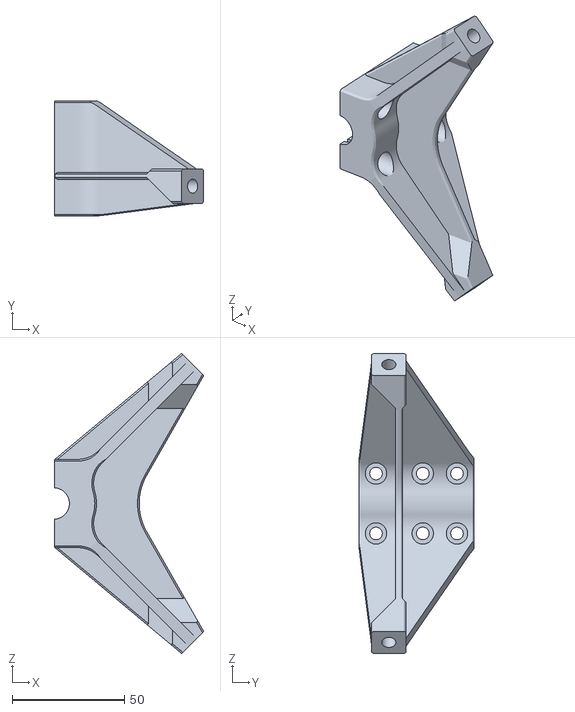
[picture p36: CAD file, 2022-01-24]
GF3 Puppetmaster Joystick Module/3D Print Files/FFB Horns, Front Half.stl
66.5 x 51.3 x 133.6

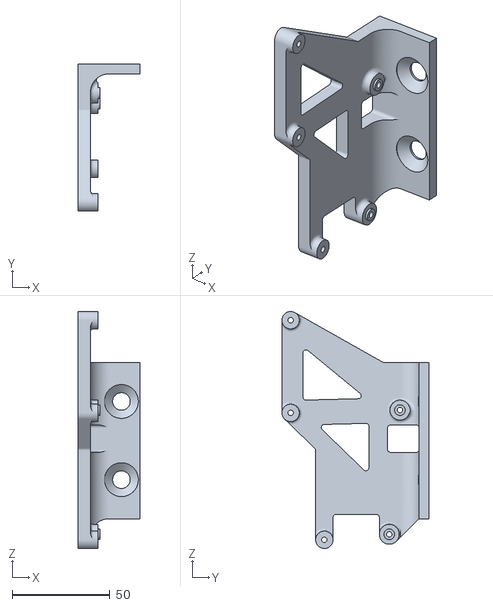
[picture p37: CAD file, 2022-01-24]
GF3 Puppetmaster Joystick Module/3D Print Files/PCB Mount.stl
31.8 x 75.2 x 121.2

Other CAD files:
K51 Collective Module/K51 Collective Module.f3z

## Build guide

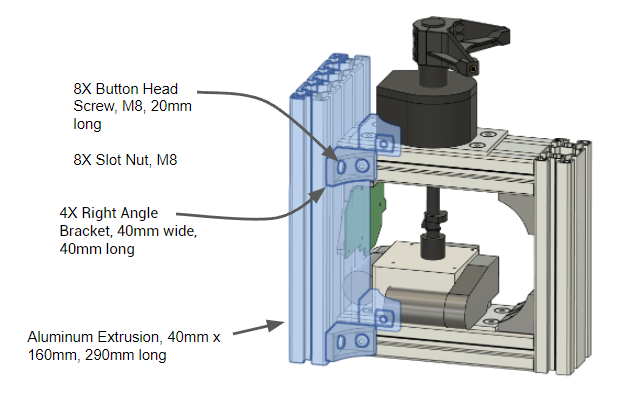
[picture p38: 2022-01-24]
GF3 Puppetmaster Joystick Module/Media/rear_beam_install.png

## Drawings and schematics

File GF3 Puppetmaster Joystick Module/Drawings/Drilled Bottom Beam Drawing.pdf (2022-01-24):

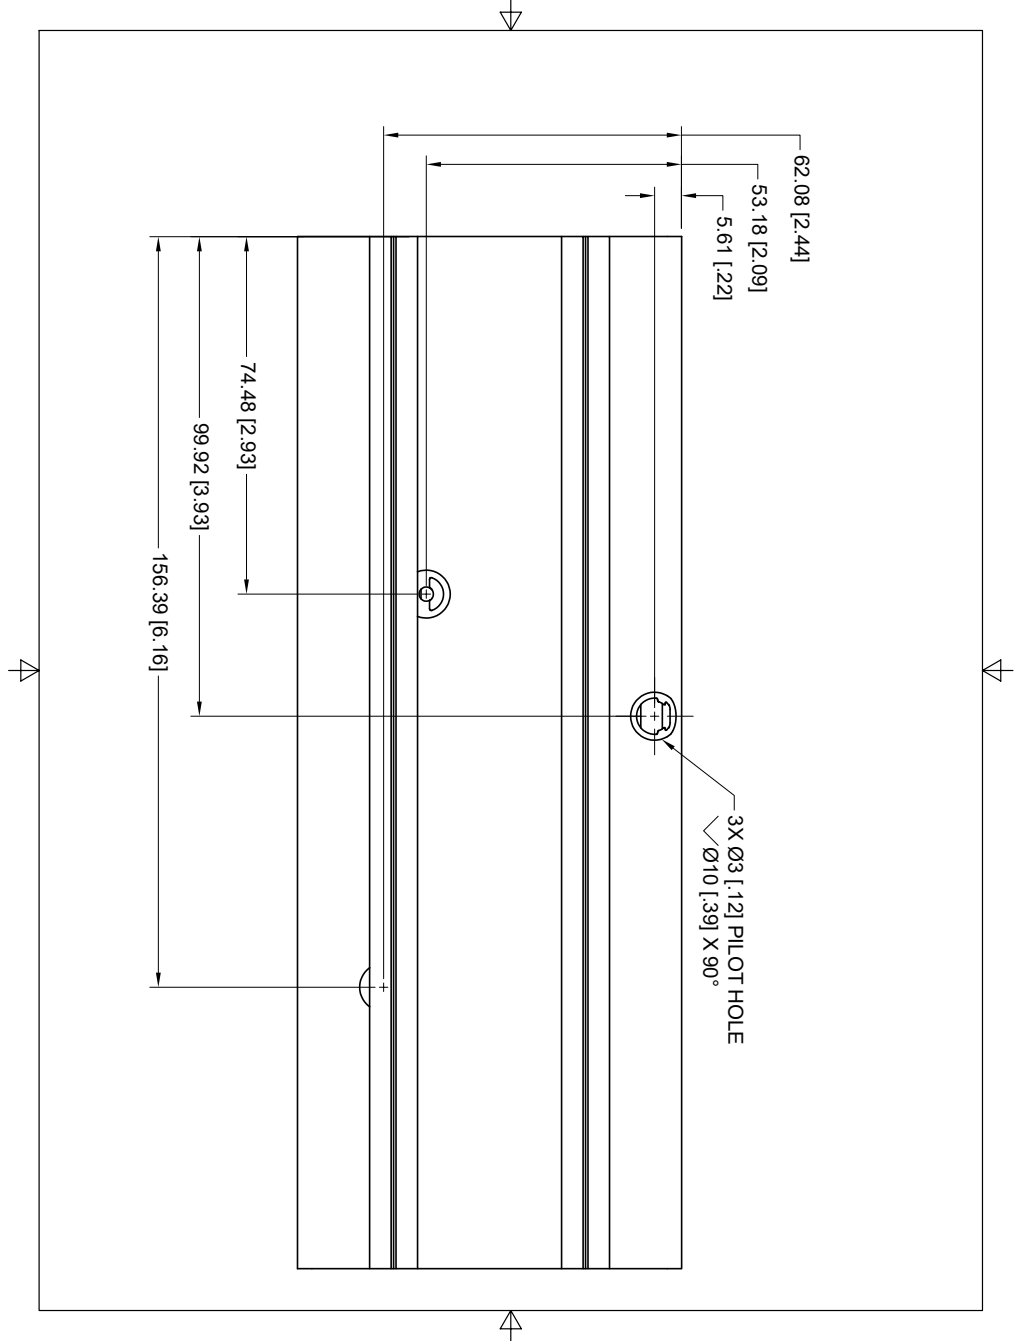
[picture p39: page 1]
156.39 [6.16] 74.48 [2.93] 99.92 [3.93] 5.61 [.22] 53.18 [2.09] 62.08 [2.44] 3X Ø3 [.12] PILOT HOLE Ø10 [.39] X 90°

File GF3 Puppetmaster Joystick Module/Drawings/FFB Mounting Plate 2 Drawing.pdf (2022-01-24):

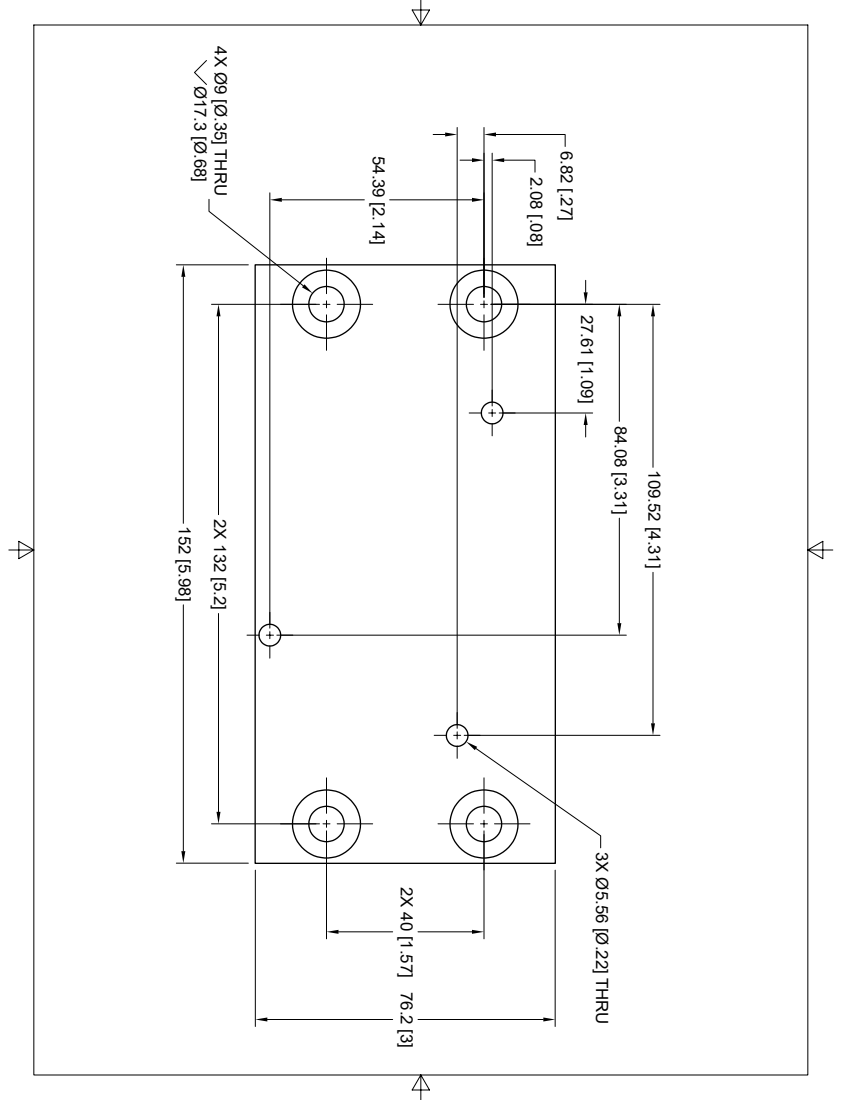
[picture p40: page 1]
152 [5.98] 76.2 [3] 2X 132 [5.2] 27.61 [1.09] 84.08 [3.31] 109.52 [4.31] 2.08 [.08] 54.39 [2.14] 6.82 [.27] 2X 40 [1.57] 4X Ø9 [Ø.35] THRU Ø17.3 [Ø.68] 3X Ø5.56 [Ø.22] THRU

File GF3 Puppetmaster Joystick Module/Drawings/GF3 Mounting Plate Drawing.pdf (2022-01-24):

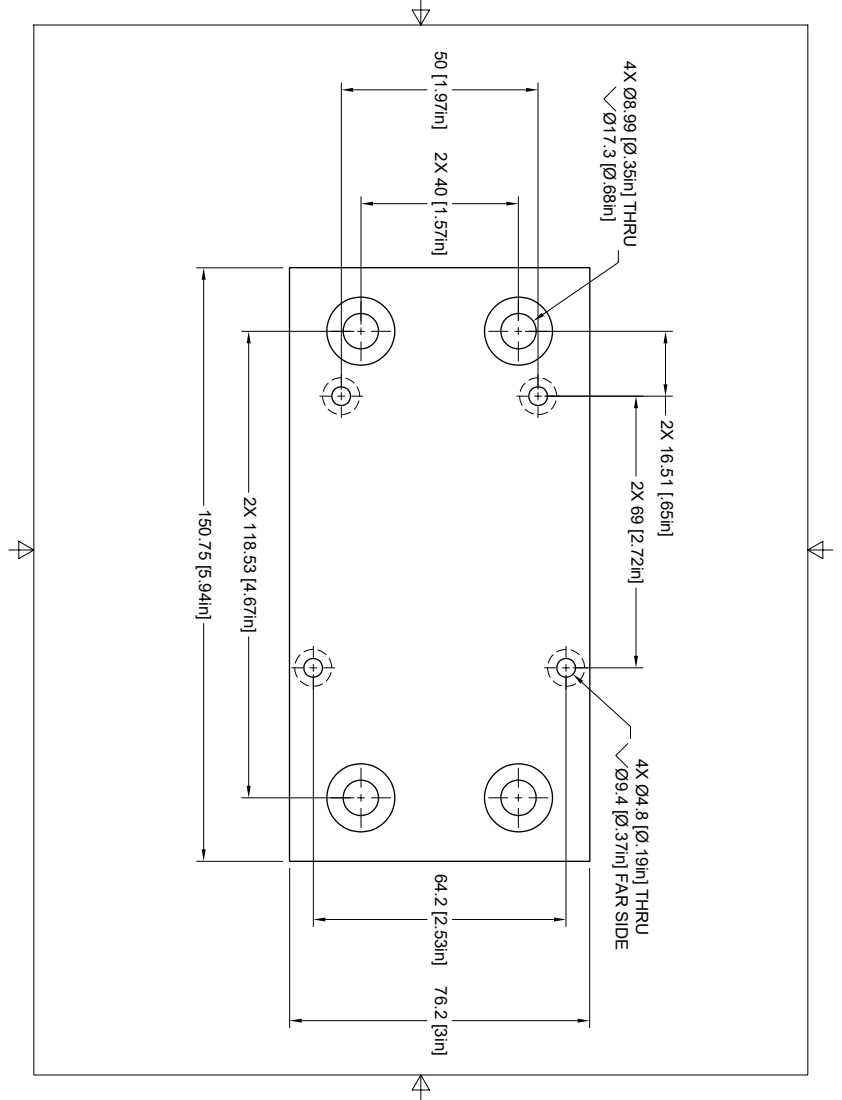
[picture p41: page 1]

4X Ø8.99 [Ø.35in] THRU Ø17.3 [Ø.68in] 4X Ø4.8 [Ø.19in] THRU Ø9.4 [Ø.37in] FAR SIDE 76.2 [3in] 150.75 [5.94in] 2X 40 [1.57in] 2X 118.53 [4.67in] 50 [1.97in] 64.2 [2.53in] 2X 16.51 [.65in] 2X 69 [2.72in]
